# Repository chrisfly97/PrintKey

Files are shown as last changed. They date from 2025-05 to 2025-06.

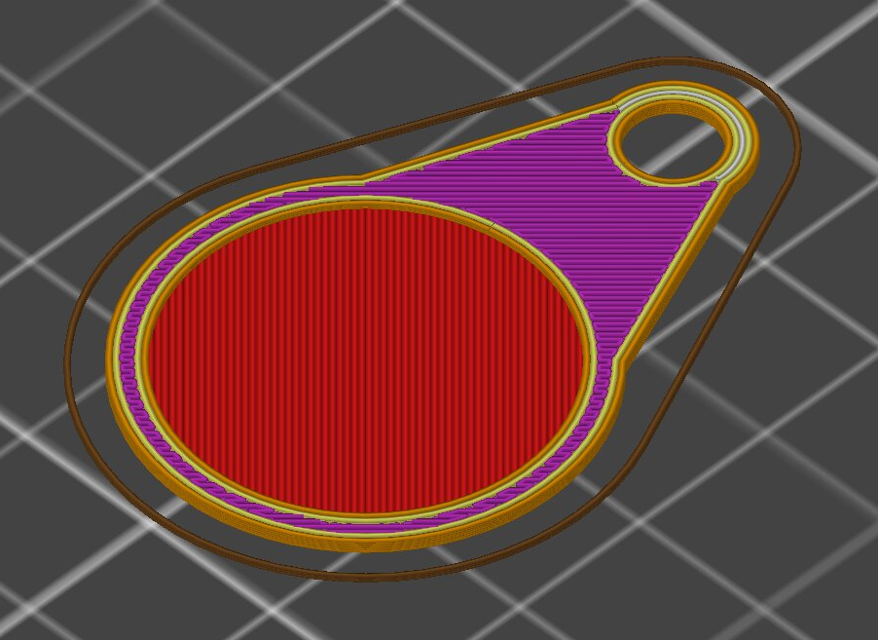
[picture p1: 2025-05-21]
3d-Druck NFC-Tag/tag.png

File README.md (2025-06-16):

Dieses Projekt wird vertreten Von
  Christoph Widner
  Lenny Stark

Das Projekt PrintKey soll eine permanete Lösung für beides Schüler und Schule werden.
Mittels diesem Projekt soll es uns möglich sein, die Drucker via NFC-Reader und 
NFC-Tag anzusteuern. Dadurch ist die Benutzerzeit der Drucker mehr Strukturiert.
Ebenso ist es dadurch nicht mehr möglich die Drucker dadurch zu missbrauchen und ohne NFC-TAG
bzw. ohne NFC-TAGS mit den richtigen Berechtigungen in einer hinterlegten Datenbank zu verwenden.
Dies soll Strom als auch Material für die Schule sparen.

Hauptprogramme: PrintKey_V1.py und user_verwalten

Tutorial zum Nachbau von PrintKay dokument Tutorial_PrintKey.docx, 
alle Programme die in diesem Dokument genannt werden findet man in dem Ordner "Programme"

Vorherige Version(en):

  -1.0 (Testprogramm V1)
  Änderungsdatum 21.05.2025

  -1.1 (Testprogramm V1.1)
   Änderungsdatum 28.05.2025

   -1.2 (Testprogramm V1.2)
   Änderungsdatum 06.06.2025

   -1.3 (Testprogramm V1.3)
    Änderungsdatum 11.06.2025

    -1.4 (PrintKeyV1.py / user_verwalten.py)
     Änderungsdatum 15.06.2025

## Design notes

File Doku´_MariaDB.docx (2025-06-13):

Doku 04.06.2025

NFC-Tags:

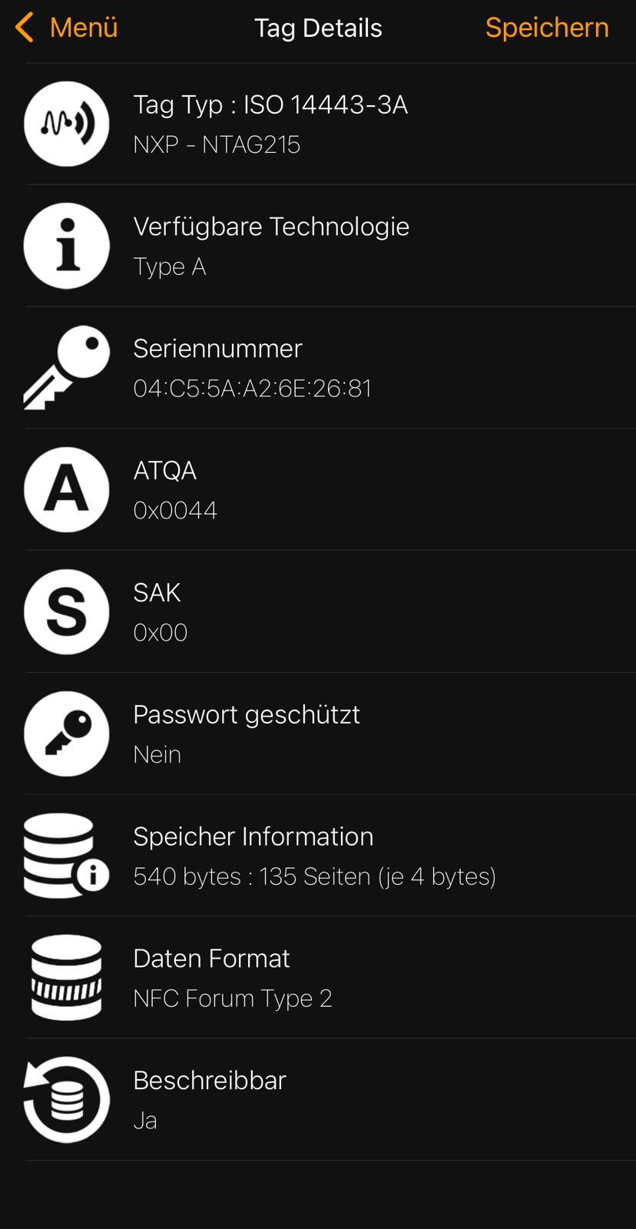
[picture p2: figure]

Diese (von Professor zur Verfügung gestellt) sind nicht mit der Standardbibliothek des MFRC522 kompatibel, deshalb werden andere Tags verwendet.

Diese sind Tags der Klasse: NTAG

Es werden Tags der Klasse MIFARE Classic 1K verwendet

Datenbank am RPI:

MariaDB auf RPI installieren:

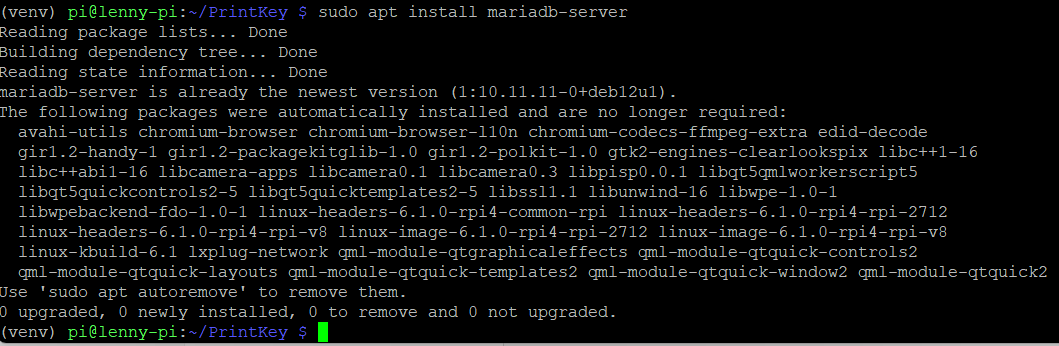
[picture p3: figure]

MariaDB starten:

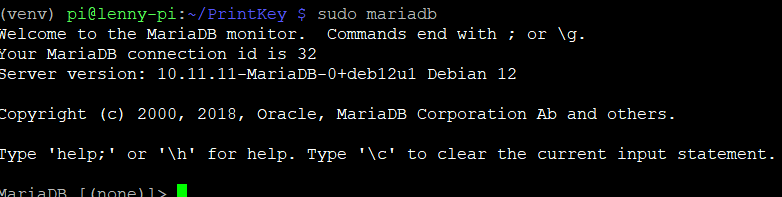
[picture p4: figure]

Datenbank Drucker_Berechtigte erstellen:

Admin erstellen (Passwort: admin) mit allen Berechtigungen:

10.06.2025

MariaDB mit Python verbinden test:

Code:

from mysql.connector import connect, Error

from getpass import getpass

try:

connection= connect(

host = "localhost",

user = input ("Enter Username"),

password = getpass ("Enter password")

)

print(connection)

except Error as e:

print(f"Fehler: {e}")

Tabelle erstellen:

Code:

from mysql.connector import connect, Error

from getpass import getpass

try:

connection= connect(

host = "localhost",

user = input ("Enter Username"),

password = getpass ("Enter password")

)

#Tabelle einfügen

cursor=connection.cursor()

cursor.execute("use Drucker_Berechtigte")

sql_query=""" Create Table if not exists berechtigte(

id int primary key auto_increment,

name varchar(100));

"""

cursor.execute(sql_query)

print("Table created: Berechtigte")

except Error as e:

print(f"Fehler: {e}")

Output:

Tabelle füllen:

Code:

from mysql.connector import connect, Error

from getpass import getpass

try:

connection= connect(

host = "localhost",

user = input ("Enter Username"),

password = getpass ("Enter password")

)

cursor=connection.cursor()

cursor.execute("use Drucker_Berechtigte")

sql_query="""INSERT INTO berechtigte (name) VALUES

('Christoph'),

('Lenny'),

('Johannes');"""

cursor.execute(sql_query)

connection.commit()

print("Database Berechtigte filled with people")

except Error as e:

print(f"Fehler: {e}")

Output:

Tabelle:

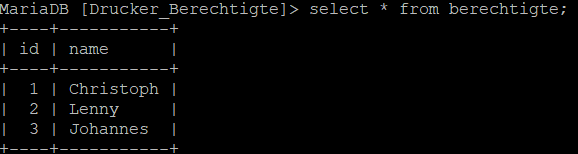
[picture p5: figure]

Lenny Stark

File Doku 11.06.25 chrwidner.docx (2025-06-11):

Doku 11.06.25 Christoph Widner

(Erste Stunde OOP-WH mit Lehrer)

Heute wurde ein 3d-Drucker und dessen aktuellen Druckstatus mittels einer LED simuliert und ein Programm geschrieben, die mittels der Drucker-Led und einer Roten Led (ausgeschalteter Zustand) und einer Grünen Led (Zustand wenn NFC Tag erkannt) das Verhalten des NFC-Readers und dem simulierten 3d Drucker beschreibt. Der dafür geschriebene Testcode für diese Simulation befindet sich unter „nfc_led_simulation.py“ auf GitHub.

Foto des Aufbaus:

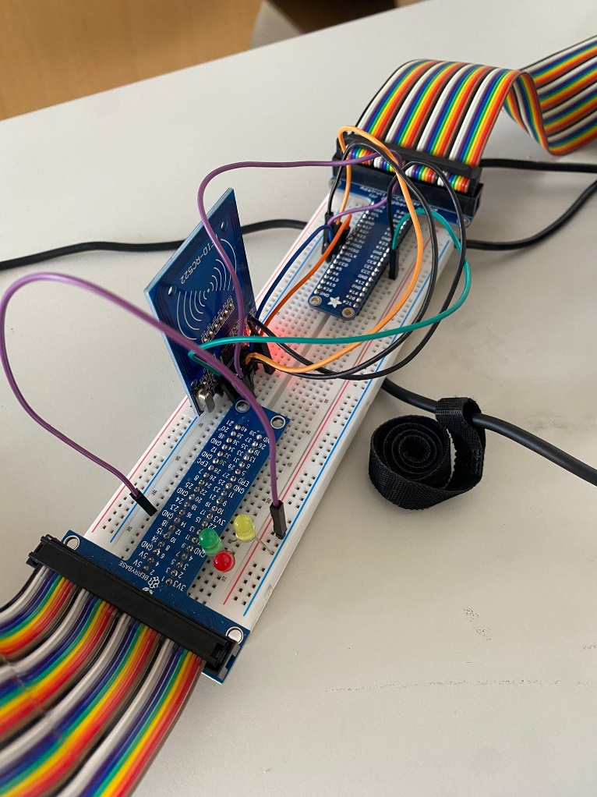
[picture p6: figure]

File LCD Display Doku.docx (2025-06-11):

QAPASS 1602A LCD-Display mit dem Raspberry PI (Doku von Christoph)

Pinout:

(Pin 1-16, an Display angeschrieben)

LCD Pin | Bezeichnung | Raspberry Pi GPIO
1 | VSS (GND) | GND (Pin 6)
2 | VDD (+5V) | 5V (Pin 2)
3 | VO (Kontrast) | Potentiometer-Mitte
4 | RS (Register Select) | GPIO 26 (Pin 37)
5 | RW (Read/Write) | GND (Schreibmodus)
6 | E (Enable) | GPIO 19 (Pin 35)
11 | D4 (Data 4) | GPIO 13 (Pin 33)
12 | D5 (Data 5) | GPIO 6 (Pin 31)
13 | D6 (Data 6) | GPIO 5 (Pin 29)
14 | D7 (Data 7) | GPIO 11 (Pin 23)
15 | A (Backlight +) | 5V (Pin 2)
16 | K (Backlight -) | GND (Pin 6)

Libraries und Testprogramm:

sudo apt-get update

sudo apt-get install python3-rpi.gpio

Testprogramm:

import RPi.GPIO as GPIO

import time

# LCD Pin-Konfiguration

RS = 26

E = 19

D4 = 13

D5 = 6

D6 = 5

D7 = 11

# GPIO-Setup

GPIO.setmode(GPIO.BCM)

GPIO.setup(RS, GPIO.OUT)

GPIO.setup(E, GPIO.OUT)

GPIO.setup(D4, GPIO.OUT)

GPIO.setup(D5, GPIO.OUT)

GPIO.setup(D6, GPIO.OUT)

GPIO.setup(D7, GPIO.OUT)

def lcd_send_byte(bits, mode):

# RS auf HIGH für Daten, LOW für Befehl

GPIO.output(RS, mode)

# High-Nibble

GPIO.output(D4, bits & 0x10 == 0x10)

GPIO.output(D5, bits & 0x20 == 0x20)

GPIO.output(D6, bits & 0x40 == 0x40)

GPIO.output(D7, bits & 0x80 == 0x80)

# Enable-Puls

lcd_toggle_enable()

# Low-Nibble

GPIO.output(D4, bits & 0x01 == 0x01)

GPIO.output(D5, bits & 0x02 == 0x02)

GPIO.output(D6, bits & 0x04 == 0x04)

GPIO.output(D7, bits & 0x08 == 0x08)

lcd_toggle_enable()

def lcd_toggle_enable():

time.sleep(0.0005)

GPIO.output(E, True)

time.sleep(0.0005)

GPIO.output(E, False)

time.sleep(0.0005)

def lcd_init():

# Initialisierung im 4-Bit-Modus

lcd_send_byte(0x33, False) # 8-Bit-Modus → 4-Bit

lcd_send_byte(0x32, False) # 4-Bit-Modus

lcd_send_byte(0x28, False) # 2 Zeilen, 5x8 Pixel

lcd_send_byte(0x0C, False) # Display ein, Cursor aus

lcd_send_byte(0x01, False) # Display löschen

time.sleep(0.002) # Warten auf Löschvorgang

def lcd_string(message, line):

# Nachricht an LCD senden (Zeile 1 oder 2)

lcd_send_byte(line, False)

for char in message:

lcd_send_byte(ord(char), True)

try:

lcd_init()

lcd_string("Hallo Raspberry!", 0x80) # Zeile 1

lcd_string("LCD funktioniert!", 0xC0) # Zeile 2

time.sleep(5)

except KeyboardInterrupt:

pass

finally:

GPIO.cleanup()

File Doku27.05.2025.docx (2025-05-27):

Dokumentation vom 21.05.2025

Heute zu erledigenden Aufgaben:

-Bauteile ermitteln

-Schaltung entwerfen und aufbauen

-RasberryPI mit dem Python-Test-Programm (Dokumentation.docx) auf GitHub testen

Aufgabenbereich Christoph:

Hardware gesucht und organisiert:

Bauteil | Menge | Beschreibung
Raspberry Pi | 1 | z. B. Pi 3, 4, oder Zero W
MFRC522 RFID/NFC | 1 | SPI-fähiger NFC-Leser
RFID/NFC-Tag | 1+ | Kompatibler Tag (MIFARE Classic etc.)
LED (grün) | 1 | Signal-LED
LED (rot) | 1 | Signal-LED
220 Ω Widerstände | 2 | Für die LEDs
Breadboard | 1 | Optional
Jumper-Kabel | mehrere | Für die GPIO-Verbindungen

Schaltung erstellt und aufgebaut:

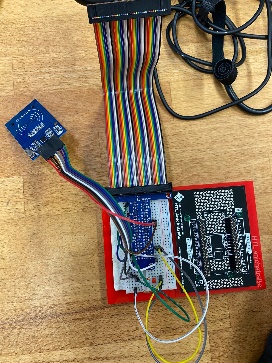
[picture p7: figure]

Aufgabenbereich Lenny:

-RasperryPi: virtual Environment erstellt darin alle nötigen Bibliotheken installiert, SPI aktiviert am Rasberry Pi,

Bibliotheken:

SPI: install spidev

MFRC522: install mfrc522

FEHLER: Das Programm hat ohne Fehlermeldungen funktioniert aber der Tag wurde nicht beschrieben

Daraufhin wurde die Schaltung mehrmals überprüft und neu aufgebaut. Die Art der NFC-Tags wurde mit der App „NFC Tools“ überprüft, diese waren kompatibel mit dem MFRC522

Ich habe während der Fehlersuche keine Screenshots am RPI gemacht, im ChatGPT Chat ist einsehbar was ich unter anderem versucht habe

Vermutung NFC-Reader MFRC522 müsste defekt sein:

Nächster Lösungsansatz:

Falls mfrc522 nicht funktioniert, kann alternativ MFRC522 von GitHub installiert werden:

git clone https://github.com/pimylifeup/MFRC522-python.git

cd MFRC522-python

Fehler! Kein Text mit angegebener Formatvorlage im Dokument. Seite 1 von 5

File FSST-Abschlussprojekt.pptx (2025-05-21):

## FSST-Abschlussprojekt

Christoph Martin Widner – Lenny Georg Stark

## Thema: Printkey

- Was wir fürs Thema brauchen:
- -Welchen Mikrocontroller: Raspi, Arduino
- -Welche Hardware (Sensorik, Kabel uw.)
- -Welche Hilfe von welchen Lehrern?
- - Welche Software wird benötigt? (Datenbank usw.)

## Idee:

- Es soll ein NFC-Reader mit einer Datenbank verbunden werden, welche überprüft ob der der vorgelegte NFC Chip in der Datenbank hinterlegt ist. Sollte dies der Fall sein, wird mittels Raspi ein Relais gesteuert, welches den 3d Drucker mit Strom versorgt und dieser dann dementsprechend verwendet werden kann. Sobald der 3d Drucker fertig ist, wird dies mittels Sensorik erkannt und die Stromzufuhr wird gekappt. Ebenso wird sich neben dem NFC Reader ein kleines LCD Display befinden welches den Aktuellen Status des Druckers ausgibt.

## UML-Diagramm

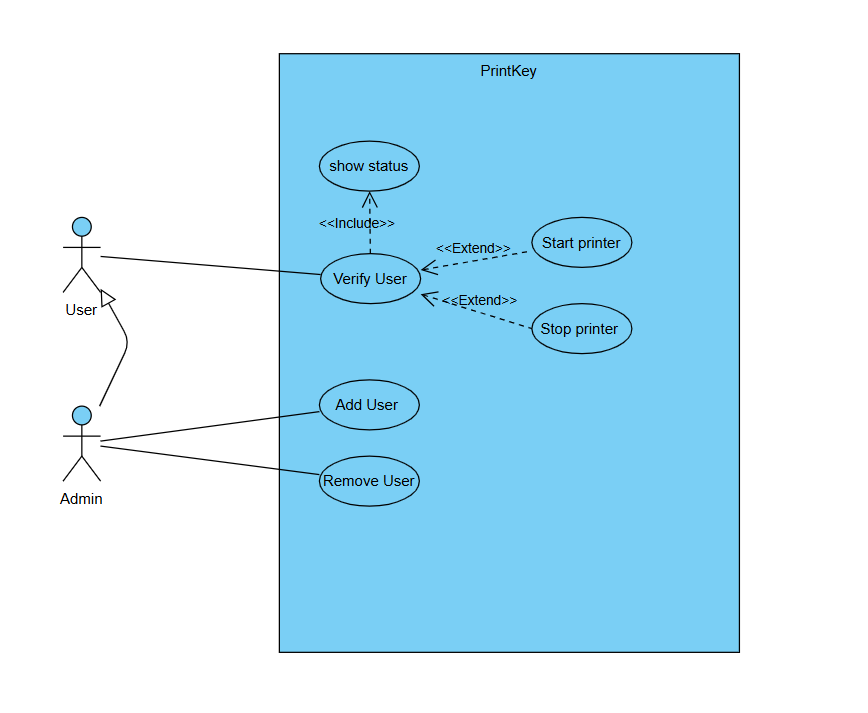
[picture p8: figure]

## Ablauf des Projektes

- 14. Mai:
  - Thema ausgesucht (PrintKey) Hilfe: LampS
  - UML-Diagramm erstellt
  - Struktur erstellt
  - GitHub aufgesetzt

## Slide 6

- 27. Mai
  - Alle nötige Hardware aussuchen und organisieren
  - Grundstruktur der Datenbank aufbauen
  - NFC Reader in Kombination eines Relais für Drucker zum laufen bringen

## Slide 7

- 04. Juni
  - Datenbank füllen (Nutzer, Berechtigungen)
  - LCD Display für User einrichten
  - Sensorik für die Start/Stopp Dedektions des 3d-Druckers einrichten

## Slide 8

- 11. Juni
  - Zeitbuffer
  - Letzter Feinschliff (Kommentare im Code, Dokumentation)

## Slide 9

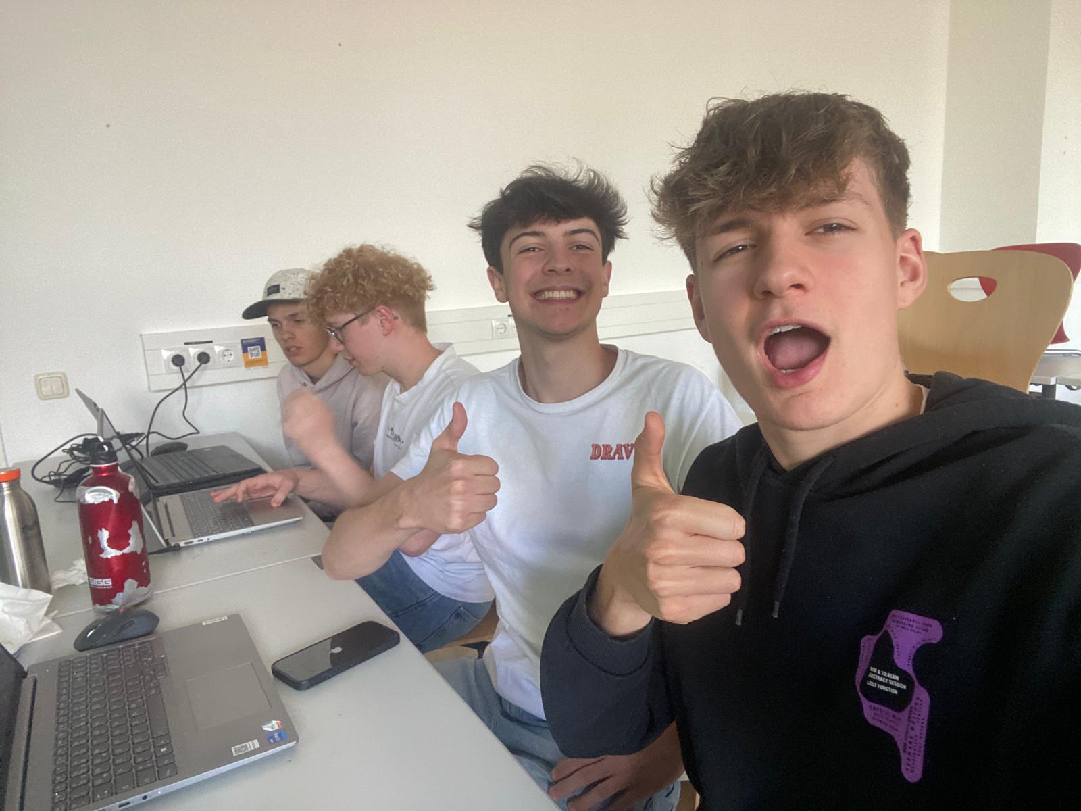
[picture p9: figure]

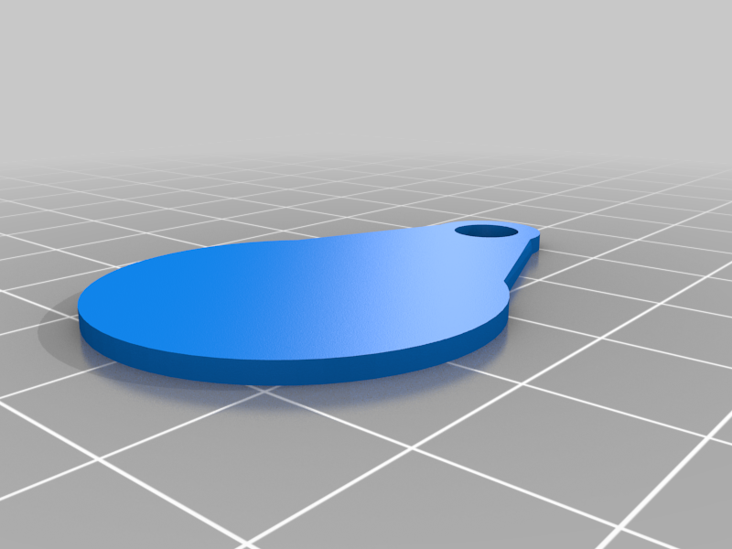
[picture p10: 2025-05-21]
3d-Druck NFC-Tag/810ab59d1282bff2c3fc6fa9f8edb73c.png

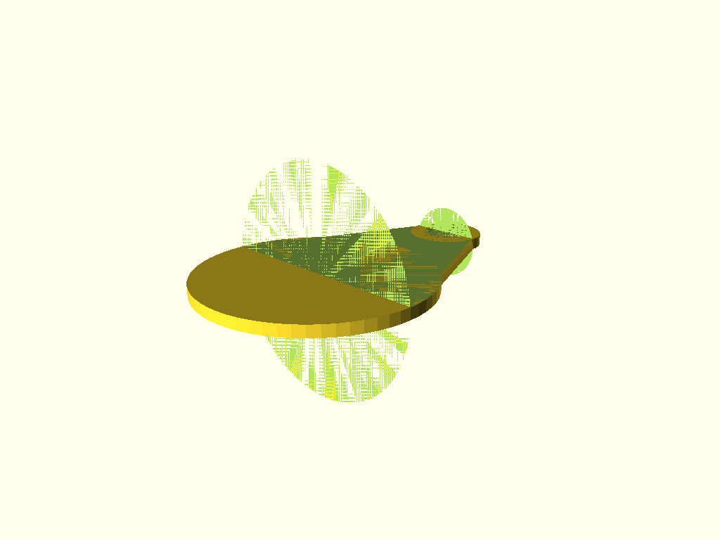
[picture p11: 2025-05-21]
3d-Druck NFC-Tag/e9140050dc927d3461dd5cc5d4c50e91.png

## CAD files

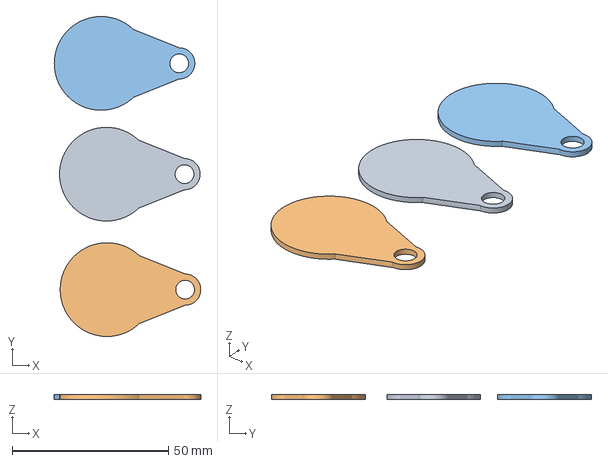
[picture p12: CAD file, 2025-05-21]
3d-Druck NFC-Tag/tag.3mf
46.9 x 102.4 x 1.50 mm
tag.stl x 3

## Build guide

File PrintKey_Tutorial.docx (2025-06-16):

PrintKey Tutorial

Inhaltsverzeichnis:

1. Bauteilliste
2. Pinout
3. SQL auf RPI aktivieren
4. SPI und I2C aktivieren
5. Benötigte Bibliotheken
6. Einzelne Bauteile testen
7. Finales Produkt
1. Bauteilliste:
- RasberryPi 4
- MFRC522
- SH1106
- 3x 5mm LED (rot, gelb, grün)
- 3x 1kΩ Widerstand
2. Pinout:

MFRC522:

RPi | MFRC522
Pin 24 / GPIO08 | SDA
Pin 23 / GPIO11 | SCK
Pin 19 / GPIO10 | MOSI
Pin 21 / GPIO09 | MISO
- | IRQ
Pin 25 / GND | GND
Pin 22 / GPIO25 | RST
Pin 17 / 3V3 | 3.3V

SH1106:

RPi | SH1106
Pin 3 / SDA | SDA
Pin 5 / SCL | SCL
Pin 1 / 3.3V | VCC
Pin 14 / GND | GND

LEDs:

RPi | LEDs
Pin 11 / GPIO 17 | Rot
Pin 13 / GPIO 27 | Grün
Pin 15 / GPIO 22 | Gelb

Anderer Pin mit Widerstand auf GND

3. SQL auf RPI aktivieren:

Siehe Dokument „Doku_MariaDB.docx“ auf GitHub

4. SPI und I2C aktivieren:

Folge dem Tutorial auf dieser Website:

How to Enable SPI/I2C on Raspberry Pi (And What to Use Them For) - MEFMobile (https://mefmobile.org/how-to-enable-spi-i2c-on-raspberry-pi-and-what-to-use-them-for/)

5. Benötigte Bibliotheken:

(installieren mit pip3 install …)

- RPi.GPIO
- mfrc522
- mysql-connector-python
- luma.oled
- spidev
6. Einzelne Bauteile testen:

Bauteile laut 2. Pinout verkabeln und folgende Programme zum Testen verwenden:

App zur Bestimmung des NFC-Tags:

NFC Tools

MFRC522 (Tags der Klasse MIFARE Classic 1K verwenden):

beschreiben_test.py

lesen_test.py

nfc_info.py

SH1106:

display_test.py (Programm sollte für 3 Sekunden „Hello World“ anzeigen)

7. Finales Produkt:

Finale Programme für aufgebaute Schaltung:

PrintKey_V1.py: Programm das NFC Tag einliest und überprüft ob user berechtigt ist zu Drucken

user_verwalten.py: Programm,um user zu verwalten, user zur Datenbank hinzufügen und Beschreiben und diese auch auf den NFC-Tag schreibt oder löscht.

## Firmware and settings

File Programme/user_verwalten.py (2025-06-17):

from mysql.connector import connect, Error
from getpass import getpass
import RPi.GPIO as GPIO
from mfrc522 import SimpleMFRC522


def get_name():
    reader = SimpleMFRC522()

    try:
        print("Bitte Tag auflegen...")
        id, text = reader.read()
        return text.strip()  #text ist ein string

    except Error as e:
        print(f"Fehler: {e}")


def tag_beschreiben(name):
    reader = SimpleMFRC522()
    try:
        print("Halten sie den neuen Tag an den Reader")
        reader.write(name)
        print(f"User {name} erfolgreich hinzugefügt")
            
    finally:
        GPIO.cleanup()

def tag_reset():
    reader = SimpleMFRC522()
    try:
        reader.write("")    
        print("Tag wurde zurückgesetzt") 
    finally:
        GPIO.cleanup()

def user_hinzufuegen(name):
    try:
        # Prüfen, ob der Name bereits existiert
        cursor.execute("SELECT * FROM berechtigte WHERE name = %s", (name,)) #Berechtigte nach namen durchsuchen
        if cursor.fetchone(): #fetchone nimmt die erste zeile wo es vorhanden ist und gibt diese als Tupel zurück wann nicht vorhanden None
            print(f"Der Name {name} existiert bereits!")
            tag_beschreiben(name)
        else:
            # Name hinzufügen
            cursor.execute("INSERT INTO berechtigte (name) VALUES (%s)", (name,)) 
            connection.commit()
            print(f"Name {name} erfolgreich hinzugefügt!")
            tag_beschreiben(name)
    except Error as e:
        print(f"Fehler: {e}")

def user_tag_entfernen(name):
    try:
        # Prüfen, ob der Name existiert
        cursor.execute("SELECT * FROM berechtigte WHERE name = %s", (name,)) #Berechtigte nach namen durchsuchen
        if cursor.fetchone(): #fetchone nimmt die erste zeile wo es vorhanden ist und gibt diese als Tupel zurück wann nicht vorhanden None
            cursor.execute("DELETE FROM berechtigte WHERE name = %s", (name,))
            connection.commit()
            tag_reset()
            print(f"user {name} erfolgreich entfernt!")    
        else:
            print(f"Der user existiert nicht! / Tag ist leer")
    except Error as e:
        print(f"Fehler: {e}")

def user_name_entfernen(name):
    try:
        # Prüfen, ob der Name existiert
        cursor.execute("SELECT * FROM berechtigte WHERE name = %s", (name,)) #Berechtigte nach namen durchsuchen
        if cursor.fetchone(): #fetchone nimmt die erste zeile wo es vorhanden ist und gibt diese als Tupel zurück wann nicht vorhanden None
            cursor.execute("DELETE FROM berechtigte WHERE name = %s", (name,))
            connection.commit()
            print(f"user {name} erfolgreich entfernt!")    
        else:
            print(f"Der user existiert nicht! / Tag ist leer")
    except Error as e:
        print(f"Fehler: {e}")


try:
    print("Mit Datenbank verbinden:")
    connection= connect(
        host = "localhost",
        user = input ("Enter Username: "),
        password = getpass ("Enter password: ")
    )
    cursor=connection.cursor()
    cursor.execute("use Drucker_Berechtigte")

except Error as e:
    print(f"Verbindungsfehler: {e}")

while True:
    print("\nMöglichkeiten: add / remove wt (tag) / remove wn (name) / cancel")
    admin_input = input("Was möchten Sie machen: ")
    if admin_input == "add":
        name = input("Name des neuen users: ")
        user_hinzufuegen(name)
    elif admin_input == "remove wt":
        name = get_name()
        user_tag_entfernen(name)
    elif admin_input == "remove wn":
        name = input("Welchen user wollen sie entfernen? ")
        user_name_entfernen(name)
    elif admin_input == "cancel":
        print("Programm wird beendet")
        break
    else: 
        print("Falscher input")

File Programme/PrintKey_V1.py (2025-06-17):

from mfrc522 import SimpleMFRC522
from mysql.connector import connect, Error
import RPi.GPIO as GPIO
from luma.core.interface.serial import i2c
from luma.core.render import canvas
from luma.oled.device import sh1106
from luma.core.error import DeviceNotFoundError
import time

# Diplay einrichten
serial = i2c(port=1, address=0x3C)
device = sh1106(serial)

# GPIO-Pins definieren
GREEN_LED_PIN = 27   # Scan möglich
YELLOW_LED_PIN = 22  # 3D-Druck läuft
RED_LED_PIN = 17     # Kein Scan möglich
GPIO.setmode(GPIO.BCM)
GPIO.setwarnings(False)

def Ausgangsstellung():
    GPIO.setup(GREEN_LED_PIN, GPIO.OUT)
    GPIO.setup(RED_LED_PIN, GPIO.OUT)
    GPIO.setup(YELLOW_LED_PIN, GPIO.OUT)

    GPIO.output(GREEN_LED_PIN, GPIO.HIGH)
    GPIO.output(YELLOW_LED_PIN, GPIO.LOW)
    GPIO.output(RED_LED_PIN, GPIO.LOW)  

    with canvas(device) as draw:
        draw.rectangle(device.bounding_box, outline="white", fill="black")
        draw.text((5, 5), "Bitte, Tag auflegen...", fill="white")

def name_suchen(suchname):
    try: 
        connection= connect(
            host = "localhost",
            user = "admin",
            password = "admin"
        )
        cursor=connection.cursor()
        cursor.execute("use Drucker_Berechtigte")
        
        # Suche nach  Übereinstimmung
        query = f"SELECT * FROM berechtigte WHERE name = %s" #%s Platzhalter für Suchname
        cursor.execute(query, (suchname,))  
        
        ergebnis = cursor.fetchall()   # ergebnis ist ein Tupel in einer Liste, [(ID,"Name")]
        cursor.close()
        connection.close()
        return ergebnis
        
    except Error as e:
        print(f"Fehler: {e}")


def get_name():
    reader = SimpleMFRC522()

    try:
        print("Bitte Tag auflegen...")
        id, text = reader.read()
        return text  #text ist ein string

    except Error as e:
        print(f"Fehler: {e}")
        

def get_drucker_state():
    GPIO.setup(YELLOW_LED_PIN, GPIO.IN)
    if GPIO.input(YELLOW_LED_PIN) == True:
        return True
    else:
        return False

try:
    while True:   
        Ausgangsstellung()
        if get_drucker_state() == False:
            GPIO.setup(YELLOW_LED_PIN, GPIO.OUT)
            ergebnis = name_suchen(get_name())

            if ergebnis != []:
                name = ergebnis[0][1]
                print(f"Hallo {name}, du darfst drucken")

                with canvas(device) as draw:
                    draw.rectangle(device.bounding_box, outline="white", fill="black")
                    draw.text((5, 5), f"Hallo, ", fill="white")
                    draw.text((5, 15), f"{name}", fill="white")
                    draw.text((5, 25), f"du darfst drucken", fill="white")
                time.sleep(3)

                with canvas(device) as draw:
                    draw.rectangle(device.bounding_box, outline="white", fill="black")
                    draw.text((5, 5), f"Drucken...", fill="white")
                
                GPIO.output(GREEN_LED_PIN, GPIO.LOW)
                GPIO.output(YELLOW_LED_PIN, GPIO.HIGH)
                GPIO.output(RED_LED_PIN, GPIO.HIGH) 
                time.sleep(10)

            else:
                print("Du darfst nicht drucken!du bist nicht berechtigt!")

                with canvas(device) as draw:
                    draw.rectangle(device.bounding_box, outline="white", fill="black")
                    draw.text((5, 5), "Du darfst nicht drucken!", fill="white")
                    draw.text((5, 25), "Du bist nicht berechtigt!", fill="white")
        
                GPIO.output(RED_LED_PIN, GPIO.HIGH) 
                GPIO.output(GREEN_LED_PIN, GPIO.LOW)
                time.sleep(5)

except KeyboardInterrupt:
    print("Programm wurde beendet")
    GPIO.output(GREEN_LED_PIN, GPIO.LOW)
    GPIO.output(YELLOW_LED_PIN, GPIO.LOW)
    GPIO.output(RED_LED_PIN, GPIO.LOW)
    GPIO.cleanup()  # Gibt die GPIOs frei

except DeviceNotFoundError as e: 
    print(f"Error: {e} Display nicht verbunden")
    GPIO.output(GREEN_LED_PIN, GPIO.HIGH)
    GPIO.output(YELLOW_LED_PIN, GPIO.HIGH)
    GPIO.output(RED_LED_PIN, GPIO.HIGH)
    time.sleep(3)
    print("Programm wurde beendet")
    GPIO.output(GREEN_LED_PIN, GPIO.LOW)
    GPIO.output(YELLOW_LED_PIN, GPIO.LOW)
    GPIO.output(RED_LED_PIN, GPIO.LOW)

except OSError as e:  
    print(f"I²C-Fehler: {e}. Überprüfe die Verbindung des Displays!")
    GPIO.output(GREEN_LED_PIN, GPIO.HIGH)
    GPIO.output(YELLOW_LED_PIN, GPIO.HIGH)
    GPIO.output(RED_LED_PIN, GPIO.HIGH)
    time.sleep(3)
    print("Programm wurde beendet")
    GPIO.output(GREEN_LED_PIN, GPIO.LOW)
    GPIO.output(YELLOW_LED_PIN, GPIO.LOW)
    GPIO.output(RED_LED_PIN, GPIO.LOW)

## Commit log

2025-05-21 Add files via upload
    Dateien hochgeladen
    [tag.3mf]
2025-06-10 Add files via upload
    Anleitung zum verwenden des QAPASS 1602A
2025-06-13 Add files via upload
    Doku zum Maria DB instalieren, Datenbank und User erstellen (mach username admin und passwort admin), drunter sein no a paar programme wo ma des connected
2025-06-16 Add files via upload
    Tutorial zum Nachbau von PrintKey
2025-06-17 PrintKey_V1 Stand 17.06.2025
